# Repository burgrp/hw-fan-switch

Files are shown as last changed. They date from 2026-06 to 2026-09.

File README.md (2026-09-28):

# hw-fan-switch

A small, wirelessly-controlled 12 V DC fan switch. It drives a fan with a
variable PWM duty cycle and is controlled over a BLE long-range radio link,
making it part of the [Bleriot](https://github.com/burgrp/bleriot) node network.

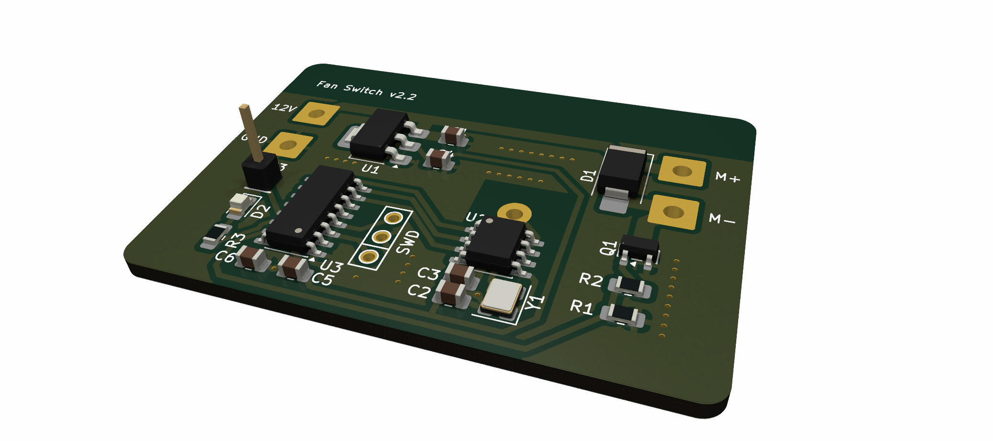
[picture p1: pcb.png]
PCB


The board is built around a **Puya PY32F003** Cortex-M0+ microcontroller with a
**PAN211x** radio, and the firmware is written in Go and compiled with
[TinyGo](https://tinygo.org/).

## Features

- Variable-speed fan control via hardware PWM (TIM14_CH1 on `PB1`).
- 50 kHz PWM carrier, above the audible range to avoid switching noise.
- Configurable low-speed handling:
  - **Low-duty threshold** — below this duty the fan is treated as stopped and
    the output is forced to 0.
  - **Low-duty kickstart** — a brief higher-duty pulse to overcome fan stiction
    when starting at low speed.
- Wireless control and telemetry over the PAN211x BLE long-range link.
- Yellow status LED is steadily on while the hub is online and flashes briefly
  once per second while offline.
- Device identity, radio settings, and configuration are owned by the site
  inventory and baked into each firmware image at build time.

## Repository layout

| Path | Description |
| --- | --- |
| `board/` | KiCad hardware design (schematic, PCB, BOM, production files). |
| `fw/` | Importable TinyGo firmware and board-owned build profile. |
| `fw/spec/` | Device specification: registers and runtime `Config`. |
| `fw/cmd/dev/` | Optional local development inventory. |
| `sub/hw-kicad/` | Shared KiCad symbol/footprint library (git submodule). |

## Hardware

| Function | Pin |
| --- | --- |
| Yellow status LED | `PB0` |
| Fan PWM output (TIM14_CH1, AF0) | `PB1` |
| Radio SPI clock | `PA2` |
| Radio SPI data | `PA1` |
| Radio SPI chip select | `PA4` |

The status LED is active high. A successfully decoded hub packet keeps the node
online for five seconds. While online the LED remains on; after the timeout it
follows BleRiot's 200 ms on, 800 ms off heartbeat until another packet arrives.

The KiCad project lives in `board/`, with fabrication outputs (Gerbers, BOM,
positions) under `board/production/`.

## Firmware

The firmware is the importable `fanswitch` package. Its TinyGo implementation
exports `Run`, while `fw/spec` exposes `Config`, the register table, chip, and a
typed build/flash profile. BleRiot generates a private external `package main`
inside the deployment module and calls `Run` with that instance's baked identity
and configuration. Nothing is generated in this repository for a deployment
build.

### Prerequisites

- [TinyGo](https://tinygo.org/getting-started/install/)
- [pyOCD](https://pyocd.io/) for flashing and RTT logging
- `arm-none-eabi-objdump` (optional, for disassembly)

Clone with submodules:

```sh
git clone --recurse-submodules https://github.com/burgrp/hw-fan-switch.git
```

### Build and flash

Build deployment firmware from the authoritative site inventory. For the AGC
checkout and its `basement.fan` instance:

```sh
cd /home/paul/git/agc/bleriot

# Inspect the generated entry point without writing it
go run . node gen --name basement.fan

# One-time: install the target CMSIS pack
go run . node install-pack --name basement.fan

# Generate the private entry point and build image.elf
go run . node build --name basement.fan

# Generate, build, flash, and open RTT
go run . node build --name basement.fan --flash --rtt

# Open RTT without flashing
go run . node rtt --name basement.fan
```

The `bleriot node` commands resolve the selected inventory instance. `node
build` generates its identity and `Config` under that deployment's private
`.bleriot` directory, then builds this module using the profile carried by
`spec.Type`. The deployment pins the firmware version in `go.mod`; it does not
carry fan-specific build flags. This repository's Makefile contains optional
aliases for `fw/cmd/dev`.

## Configuration

The inventory `Config` (see `fw/spec/spec.go`) controls runtime behaviour:

| Field | Meaning |
| --- | --- |
| `DefaultDuty` | Fan duty cycle (0–100) applied at startup. |
| `LowDutyThreshold` | Duty below which the fan is forced to 0. `0` disables the threshold. |
| `LowDutyKickstart` | Duty briefly applied to spin up the fan from low speed. `0` disables the kickstart. |

## Control interface

The device exposes a single register over the Bleriot network:

| Register | Tag | Type | Unit | Description |
| --- | --- | --- | --- | --- |
| `duty` | 1 | int | % | PWM duty cycle, 0–100. |

Writing `duty` updates the fan speed; the hub's next scheduled GET observes the
new value. A NULL write stops the fan. Reading returns the current duty.

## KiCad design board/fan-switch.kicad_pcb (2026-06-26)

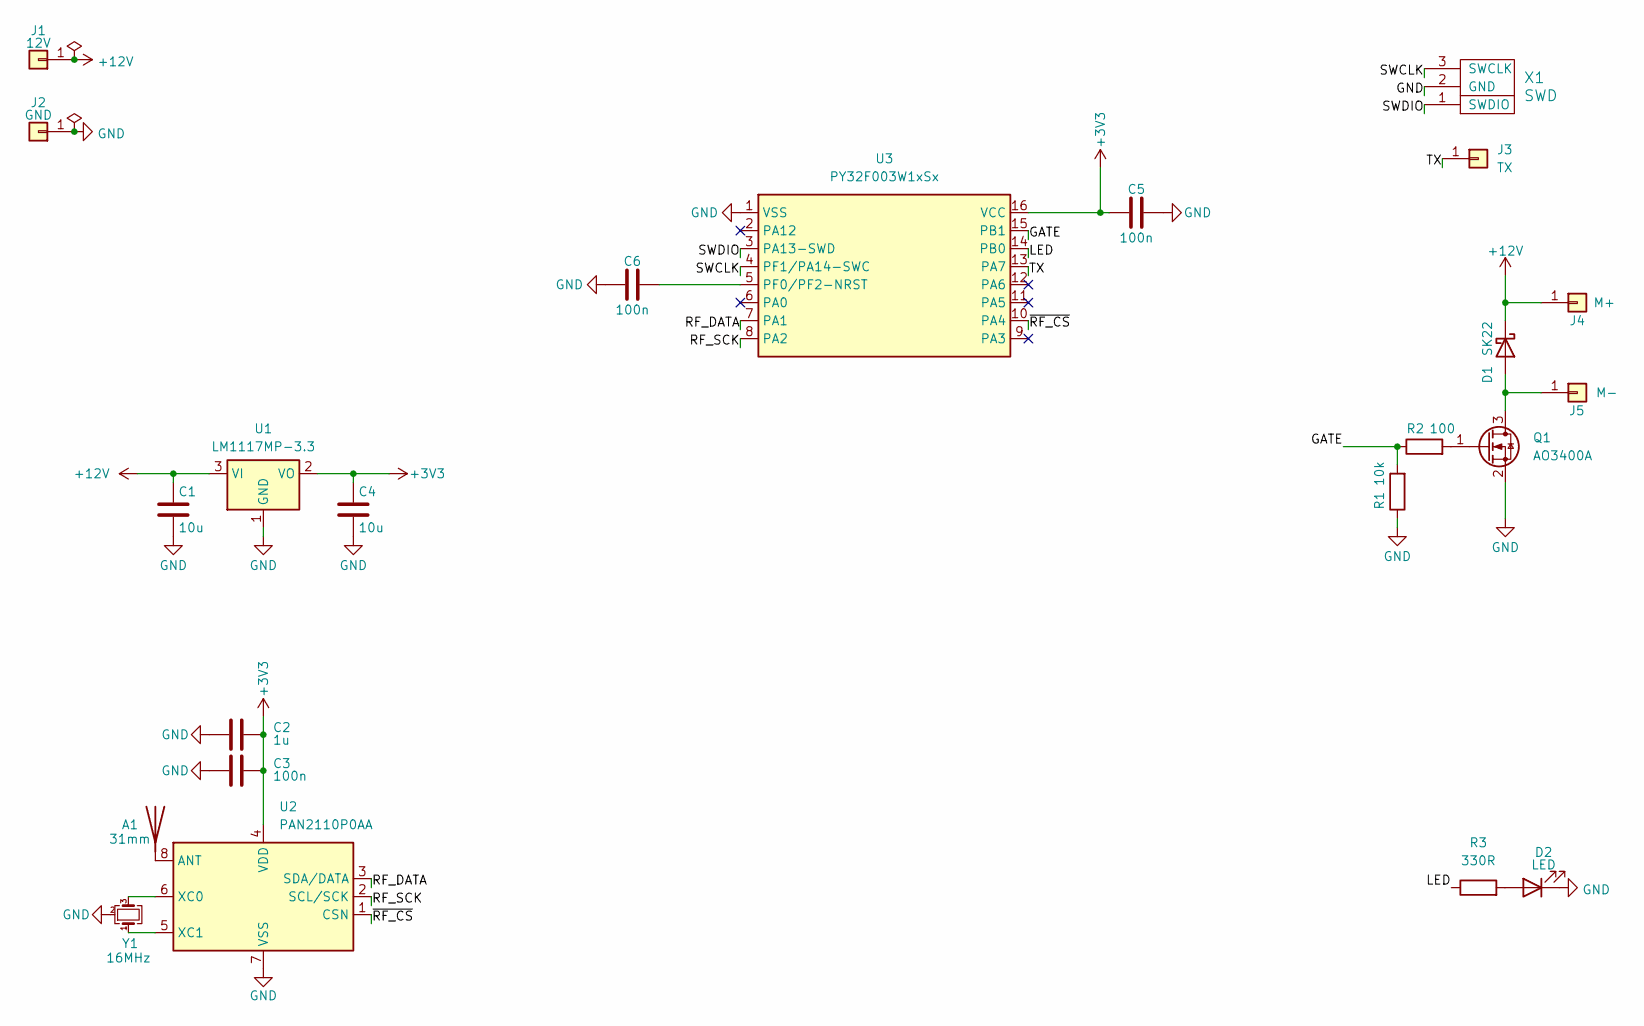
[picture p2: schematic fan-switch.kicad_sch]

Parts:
A1: 31mm; Wire antena 2.4GHz
C1, C4: 10u; C_0805_2012Metric
C2: 1u; C_0805_2012Metric
C3, C5, C6: 100n; C_0805_2012Metric
D1: SK22; D_SMB_Handsoldering
D2: LED; LED_0805_2012Metric_Pad1.15x1.40mm_HandSolder
J1: 12V; SolderWire-1sqmm_1x01_D1.4mm_OD3.9mm
J2: GND; SolderWire-1sqmm_1x01_D1.4mm_OD3.9mm
J3: TX; PinHeader_1x01_P2.54mm_Vertical
J4: M+; SolderWire-1sqmm_1x01_D1.4mm_OD3.9mm
J5: M-; SolderWire-1sqmm_1x01_D1.4mm_OD3.9mm
Q1: AO3400A; SOT-23
R1: 10k; R_0805_2012Metric_Pad1.20x1.40mm_HandSolder
R2: 100; R_0805_2012Metric_Pad1.20x1.40mm_HandSolder
R3: 330R; R_0805_2012Metric_Pad1.20x1.40mm_HandSolder
U1: LM1117MP-3.3; SOT-223-3_TabPin2
U2: PAN2110P0AA; SOIC-8_3.9x4.9mm_P1.27mm
U3: PY32F003W1xSx; SOIC-16_3.9x9.9mm_P1.27mm
X1: SWD
Y1: 16MHz; Crystal_SMD_3225-4Pin_3.2x2.5mm

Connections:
+3V3: C2.1, C3.1, C4.1, C5.1, U1.2 (VO), U2.4 (VDD), U3.16 (VCC)
+12V: C1.1, D1.1 (K), J1.1, J4.1, U1.3 (VI)
/GATE: R1.2, R2.1, U3.15 (PB1)
/LED: R3.1, U3.14 (PB0)
/RF_DATA: U2.3 (SDA/DATA), U3.7 (PA1)
/RF_SCK: U2.2 (SCL/SCK), U3.8 (PA2)
/SWCLK: U3.4 (PF1/PA14-SWC), X1.3 (SWCLK)
/SWDIO: U3.3 (PA13-SWD), X1.1 (SWDIO)
/TX: J3.1, U3.13 (PA7)
/~RF_CS: U2.1 (CSN), U3.10 (PA4)
GND: C1.2, C2.2, C3.2, C4.2, C5.2, C6.2, D2.1 (K), J2.1, Q1.2 (S), R1.1, U1.1 (GND), U2.7 (VSS), U3.1 (VSS), X1.2 (GND), Y1.2 (G), Y1.4 (G)
unnamed: A1.1 (A), U2.8 (ANT)
unnamed: D1.2 (A), J5.1, Q1.3 (D)
unnamed: D2.2 (A), R3.2
unnamed: Q1.1 (G), R2.2
unnamed: U2.6 (XC0), Y1.3
unnamed: U2.5 (XC1), Y1.1
unnamed: C6.1, U3.5 (PF0/PF2-NRST)

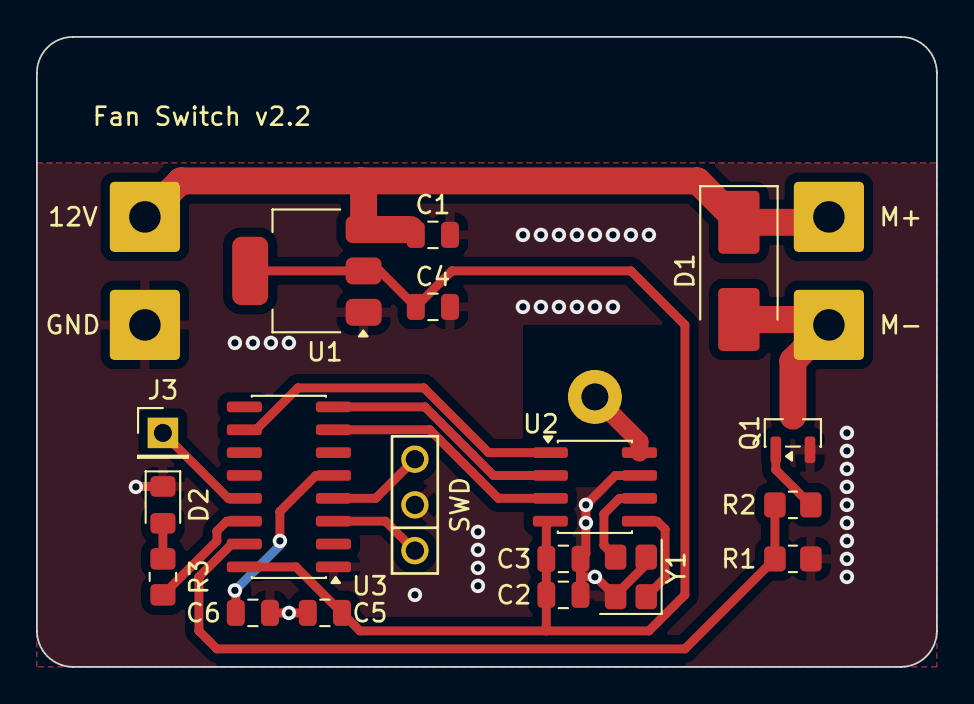
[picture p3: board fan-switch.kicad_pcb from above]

Board: 2 copper layers, 50.0 x 35.0 mm, 23 parts (0 on the bottom side), 18 nets.

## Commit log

2026-06-25 Refactor fan control firmware: update configurations, modify GPIO handling, and streamline dependencies
2026-06-26 Refactor fan control and update schematic
    - Updated fan PWM configuration in main.go to use TIM14 on PB1 with a frequency of 50 kHz.
    - Added setupFanPWM and setFanDuty methods to manage fan speed via PWM.
    - Adjusted pin assignments for SPI communication.
    - Modified the schematic to reflect new pin locations and updated component positions.
    - Changed Makefile to include new commands for project management.
    - Updated test-hub.go with new UID and Key values for the fan device.
    [fan-switch.kicad_pcb, fan-switch.kicad_sch]
2026-06-26 Update fan control logic: enable LED on duty cycle change and remove unused ledLoop function
2026-06-26 Refactor fan control: update duty cycle thresholds and add StartNode function for PAN211x radio
2026-06-26 Refactor dependency management: update go.mod and go.sum for tinygo-drivers and remove unused pan211x package
2026-06-26 Add low duty cycle configuration: introduce LowDutyThreshold and LowDutyKickstart in Config struct and update fan control logic
2026-06-26 Update dependency versions: upgrade bleriot/lib and tinygo-drivers to v1.0.0
2026-06-26 Add metadata for duty cycle unit in device type specification
2026-09-28 feat(fw)!: expose importable fan firmware
